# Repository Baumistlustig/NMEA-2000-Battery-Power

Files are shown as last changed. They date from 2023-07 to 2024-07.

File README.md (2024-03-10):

# NMEA 2000 Battery Power

This is a project, which reads the voltage and current of a battery, and posts it to a NMEA 2000 BUS.

The project uses an ESP32 & the SN65HVD230 for CAN BUS communication. If the voltage falls under a certain value, a contactor will automatically disconnect the battery from the rest of the circuit to prevent drain. 

Additionally, it posts the voltage, current and temperature into the N2k bus where it can be worked with by other devices.

## Table of Contents

- [Electrical](/Electrical) A KiCad project 
- [Software](/Software) A PlatformIO project

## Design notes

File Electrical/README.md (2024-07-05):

  # Electrical

  The KiCad project

  ## Table of Contents

  - [Symbol](/Electrical/Symbol) The Symbols for the schematics
  - [Datasheets](/Electrical/Datasheets) Datasheets of the components
  - [3D-Models](/Electrical/3D-Models) 3D-Models for the PCB
  - [Footprints](/Electrical/Footprints) Footprins for the PCB

## Components-List

A list of all the electrical components I used for the project:

- [ESP32 WROOM-32E](/Electrical/Datasheets/esp32-wroom-32e.pdf) Microcontroller
- [SN65HVD230](/Electrical/Datasheets/sn76hvd230.pdf) CAN Transceiver
- [BME280](/Electrical/Datasheets/bme280.pdf) Environment temp- & humidity sensor
- [ADS131M08](/Electrical/Datasheets/ads131m08-q1.pdf) 24-bit, 8 channel ADC
- [HO 150-S-SP30.pdf](/Electrical/Datasheets/HO-150-S-SP30.pdf) 150A current transducer
- [IRFZ44N](/Electrical/Datasheets/IRFZ44N.pdf) N-Channel MOSFET
- [LM7850](/Electrical/Datasheets/MC7800-D.PDF) 12-5V voltage regulator
- [AMS1117](/Electrical/Datasheets/ams1117.pdf) 5-3.3V voltage regulator
- [B57703M](/Electrical/Datasheets/B57703M-Thermistor.pdf) 10k NTC Thermistor
- ([ADR4533](/Electrical/Datasheets/ADR4533.pdf) 3.3V reference voltage source)

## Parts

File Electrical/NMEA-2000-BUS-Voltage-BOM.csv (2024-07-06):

Reference | Value | Datasheet | Footprint | Qty | DNP
C1,C2,C5,C6,C9,C13,C14,C16,C17,C19,C20,C23,C25,C28,C30 | 0.1uF | ~ | Capacitor_THT:C_Disc_D5.0mm_W2.5mm_P5.00mm | 15
C3,C7,C12,C15 | 20pF | ~ | Capacitor_THT:C_Disc_D5.0mm_W2.5mm_P5.00mm | 4
C4,C11 | 0.33uF | ~ | Capacitor_THT:C_Disc_D5.0mm_W2.5mm_P5.00mm | 2
C8,C21,C22,C24,C26 | 10nF | ~ | Capacitor_THT:C_Disc_D5.0mm_W2.5mm_P5.00mm | 5
C10,C27 | 1uF | ~ | Capacitor_THT:C_Disc_D5.0mm_W2.5mm_P5.00mm | 2
C18 | 0.1nF | ~ | Capacitor_THT:C_Disc_D5.0mm_W2.5mm_P5.00mm | 1
C29 | 220nF | ~ | Capacitor_THT:C_Disc_D5.0mm_W2.5mm_P5.00mm | 1
D1,D6,D7 | 1N5819 | ~ | Diode_THT:D_DO-41_SOD81_P10.16mm_Horizontal | 3
D2,D3,D4,D5 | LED | ~ | LED_THT:LED_D5.0mm | 4
F1 | Polyfuse | ~ | Diode_SMD:D_1210_3225Metric_Pad1.42x2.65mm_HandSolder | 1
IC1 | ADS131M08 | https://www.ti.com/lit/ds/symlink/ads131m08-q1.pdf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 | ADS131M08QPBSRQ1:QFP50P700X700X120-32N | 1
J1,J2,J4 | Conn_01x04 | ~ | -- mixed values -- | 3
J3 | Conn_02x08_Counter_Clockwise | ~ | Connector_PinHeader_2.54mm:PinHeader_2x09_P2.54mm_Vertical | 1
J5,J6,J11 | Conn_01x05 | ~ | -- mixed values -- | 3
J7,J8,J9,J10,J12,J13 | Conn_01x02 | ~ | TerminalBlock_Phoenix:TerminalBlock_Phoenix_PT-1,5-2-5.0-H_1x02_P5.00mm_Horizontal | 6
JP1,JP2 | Jumper_2_Open | ~ | Connector_PinHeader_2.54mm:PinHeader_1x02_P2.54mm_Vertical | 2
JP6,JP7 | Jumper_2_Bridged | ~ | Connector_PinHeader_2.54mm:PinHeader_1x02_P2.54mm_Vertical | 2
L1 | CBG322513U102T | ~ | Inductor_SMD:L_1210_3225Metric_Pad1.42x2.65mm_HandSolder | 1
Q1,Q2 | IRFZ44N | https://www.infineon.com/dgdl/Infineon-IRFZ44N-DataSheet-v01_01-EN.pdf?fileId=5546d462533600a40153563b3a9f220d | Package_TO_SOT_THT:TO-220-3_Vertical | 2
R1,R3,R9,R11,R13,R14,R15,R17,R18,R25,R26 | 10k | ~ | Resistor_THT:R_Axial_DIN0207_L6.3mm_D2.5mm_P10.16mm_Horizontal | 11
R2 | 0R | ~ | Resistor_THT:R_Axial_DIN0207_L6.3mm_D2.5mm_P10.16mm_Horizontal | 1
R4 | 1.2k | ~ | Resistor_THT:R_Axial_DIN0207_L6.3mm_D2.5mm_P10.16mm_Horizontal | 1
R5 | 470R | ~ | Resistor_THT:R_Axial_DIN0207_L6.3mm_D2.5mm_P10.16mm_Horizontal | 1
R6 | 330R | ~ | Resistor_THT:R_Axial_DIN0207_L6.3mm_D2.5mm_P10.16mm_Horizontal | 1
R7 | 1k5 | ~ | Resistor_THT:R_Axial_DIN0207_L6.3mm_D2.5mm_P10.16mm_Horizontal | 1
R8,R23,R24 | 120R | ~ | Resistor_THT:R_Axial_DIN0207_L6.3mm_D2.5mm_P10.16mm_Horizontal | 3
R10 | 3.3k | ~ | Resistor_THT:R_Axial_DIN0207_L6.3mm_D2.5mm_P10.16mm_Horizontal | 1
R12,R16 | 4k7 | ~ | Resistor_THT:R_Axial_DIN0207_L6.3mm_D2.5mm_P10.16mm_Horizontal | 2
R19,R20,R21,R22 | 1k | ~ | Resistor_THT:R_Axial_DIN0207_L6.3mm_D2.5mm_P10.16mm_Horizontal | 4
SW1,SW2 | SW_Push | ~ | Button_Switch_THT:SW_PUSH_6mm | 2
TP1 | 12V | ~ | TestPoint:TestPoint_Pad_3.0x3.0mm | 1
TP2 | 5V | ~ | TestPoint:TestPoint_Pad_3.0x3.0mm | 1
TP3 | 3.3V | ~ | TestPoint:TestPoint_Pad_3.0x3.0mm | 1
TP4 | VMot | ~ | TestPoint:TestPoint_Pad_3.0x3.0mm | 1
U1 | LM7805_TO220 | https://www.onsemi.cn/PowerSolutions/document/MC7800-D.PDF | Package_TO_SOT_THT:TO-220-3_Vertical | 1
U2 | AMS1117-3.3 | http://www.advanced-monolithic.com/pdf/ds1117.pdf | Package_TO_SOT_SMD:SOT-223-3_TabPin2 | 1
U3 | STM32G431CBTx | https://www.st.com/resource/en/datasheet/stm32g431cb.pdf | Package_QFP:LQFP-48_7x7mm_P0.5mm | 1
U4 | MCP2562-E-P | http://ww1.microchip.com/downloads/en/DeviceDoc/25167A.pdf | Package_DIP:DIP-8_W7.62mm | 1
U5 | BMP280 | https://ae-bst.resource.bosch.com/media/_tech/media/datasheets/BST-BMP280-DS001.pdf | N2K-influx:Bosch_LGA-8_2x2.5mm_P0.65mm_ClockwisePinNumbering | 1
U6 | ADR4533 | https://www.analog.com/media/en/technical-documentation/data-sheets/ADR4520_4525_4530_4533_4540_4550.pdf | Package_SO:SOIC-8_3.9x4.9mm_P1.27mm | 1
Y1 | K7A080002020 | ~ | Crystal:Crystal_SMD_7050-4Pin_7.0x5.0mm | 1
Y2 | X308032768KGB2SC | ~ | Crystal:Crystal_C38-LF_D3.0mm_L8.0mm_Horizontal | 1
Y3 | 20kHz Crystal | ~ | Crystal:Crystal_AT310_D3.0mm_L10.0mm_Horizontal | 1

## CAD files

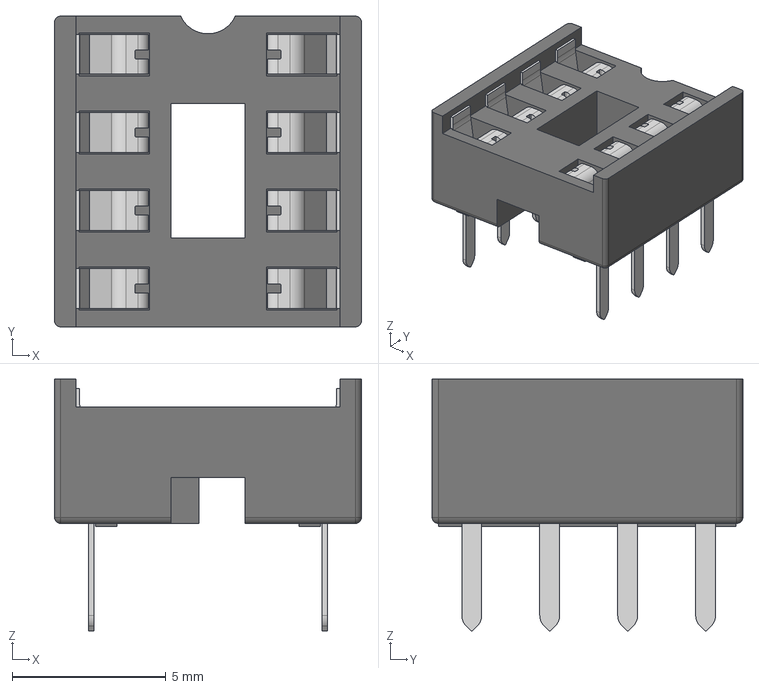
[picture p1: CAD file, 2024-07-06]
Electrical/3D-Models/Socket_DIP8.stp
10.0 x 10.1 x 8.20 mm

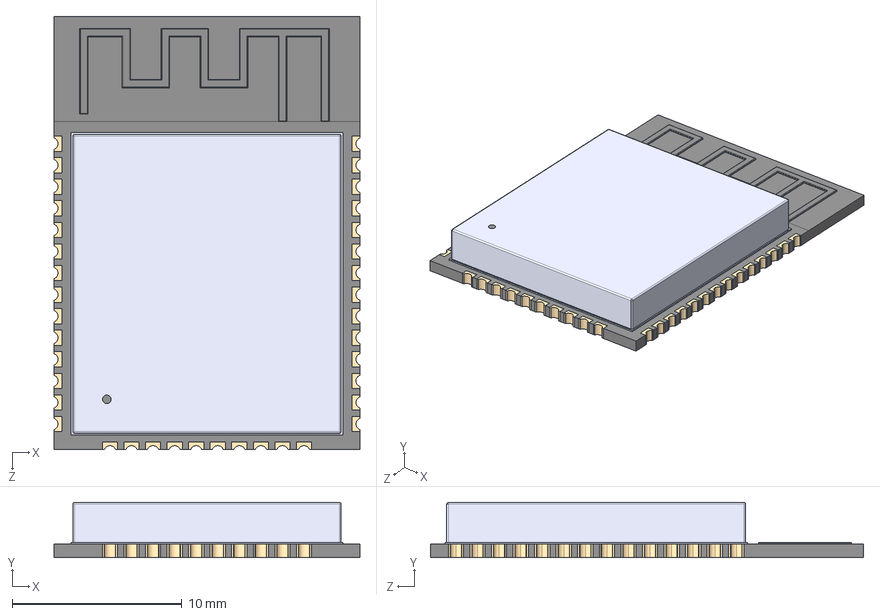
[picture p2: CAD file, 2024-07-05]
Electrical/3D-Models/ESP32-WROOM-32E (16MB).STEP
18.0 x 3.25 x 25.5 mm

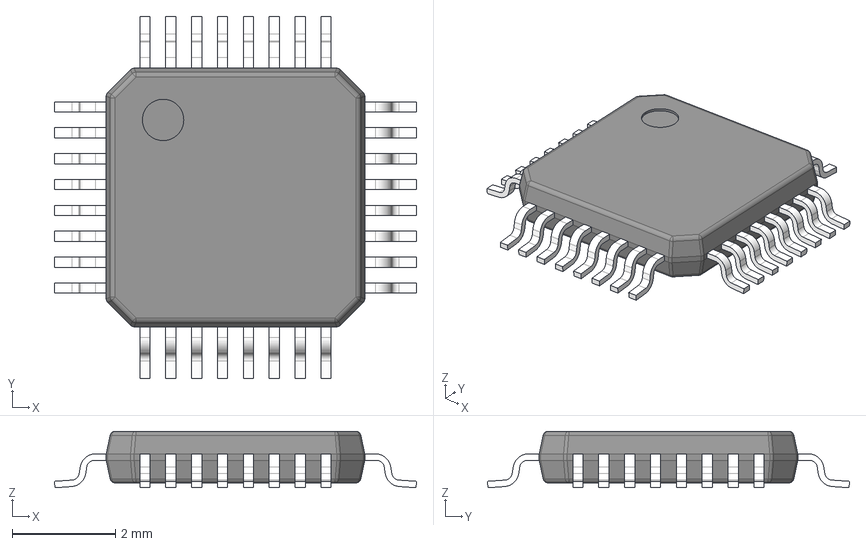
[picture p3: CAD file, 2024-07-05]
Electrical/3D-Models/ADS131M08QPBSRQ1.stp
7.00 x 7.00 x 1.09 mm
BODY-TQFP
LEAD-TQFP x 32
PIN1

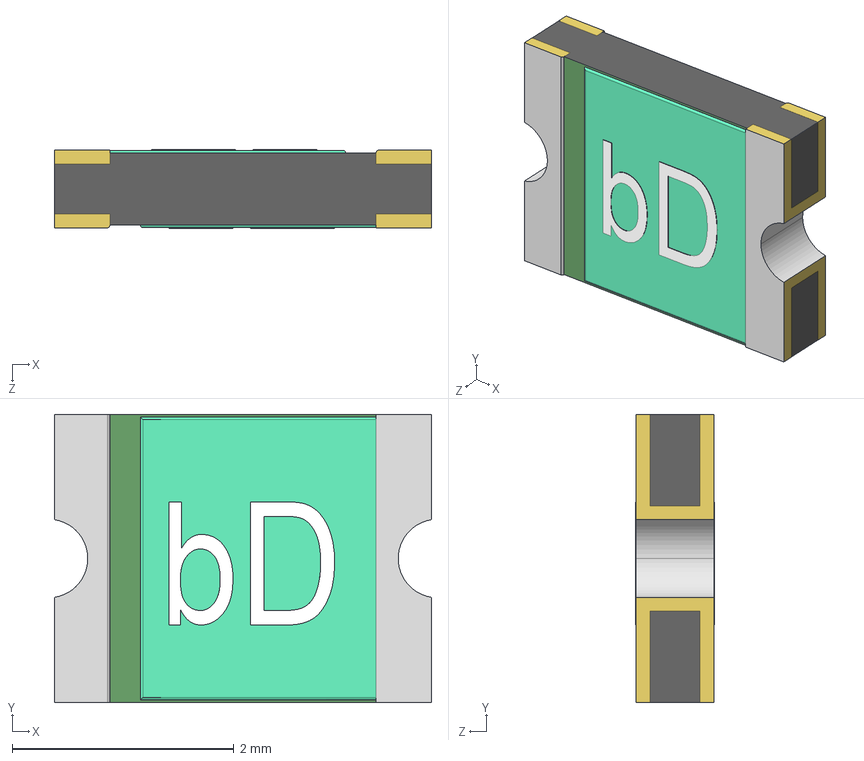
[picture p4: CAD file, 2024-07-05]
Electrical/3D-Models/Resetable Fuse 1210.step
3.40 x 2.60 x 0.708 mm

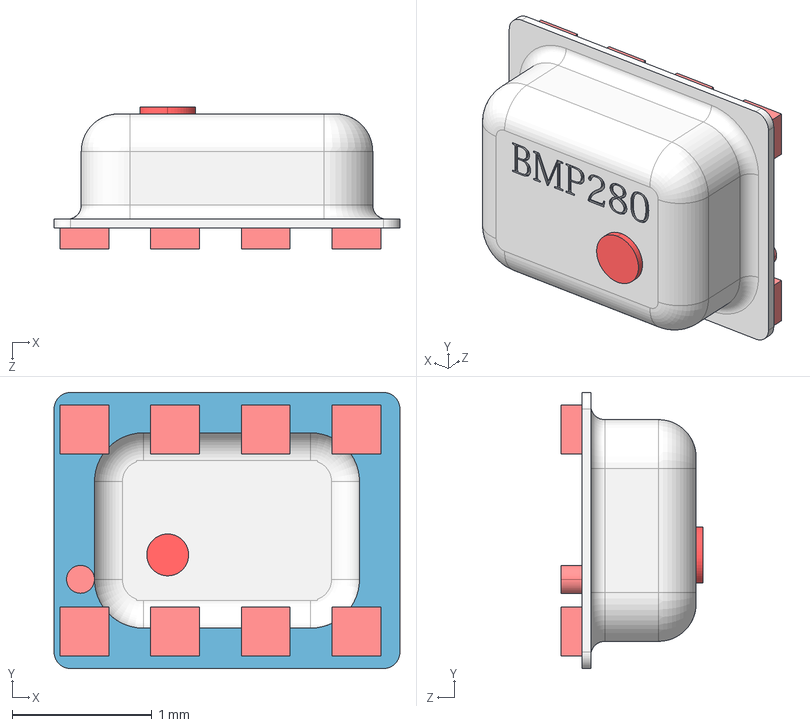
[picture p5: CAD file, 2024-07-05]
Electrical/3D-Models/BMP-280.STEP
2.48 x 1.98 x 1.02 mm

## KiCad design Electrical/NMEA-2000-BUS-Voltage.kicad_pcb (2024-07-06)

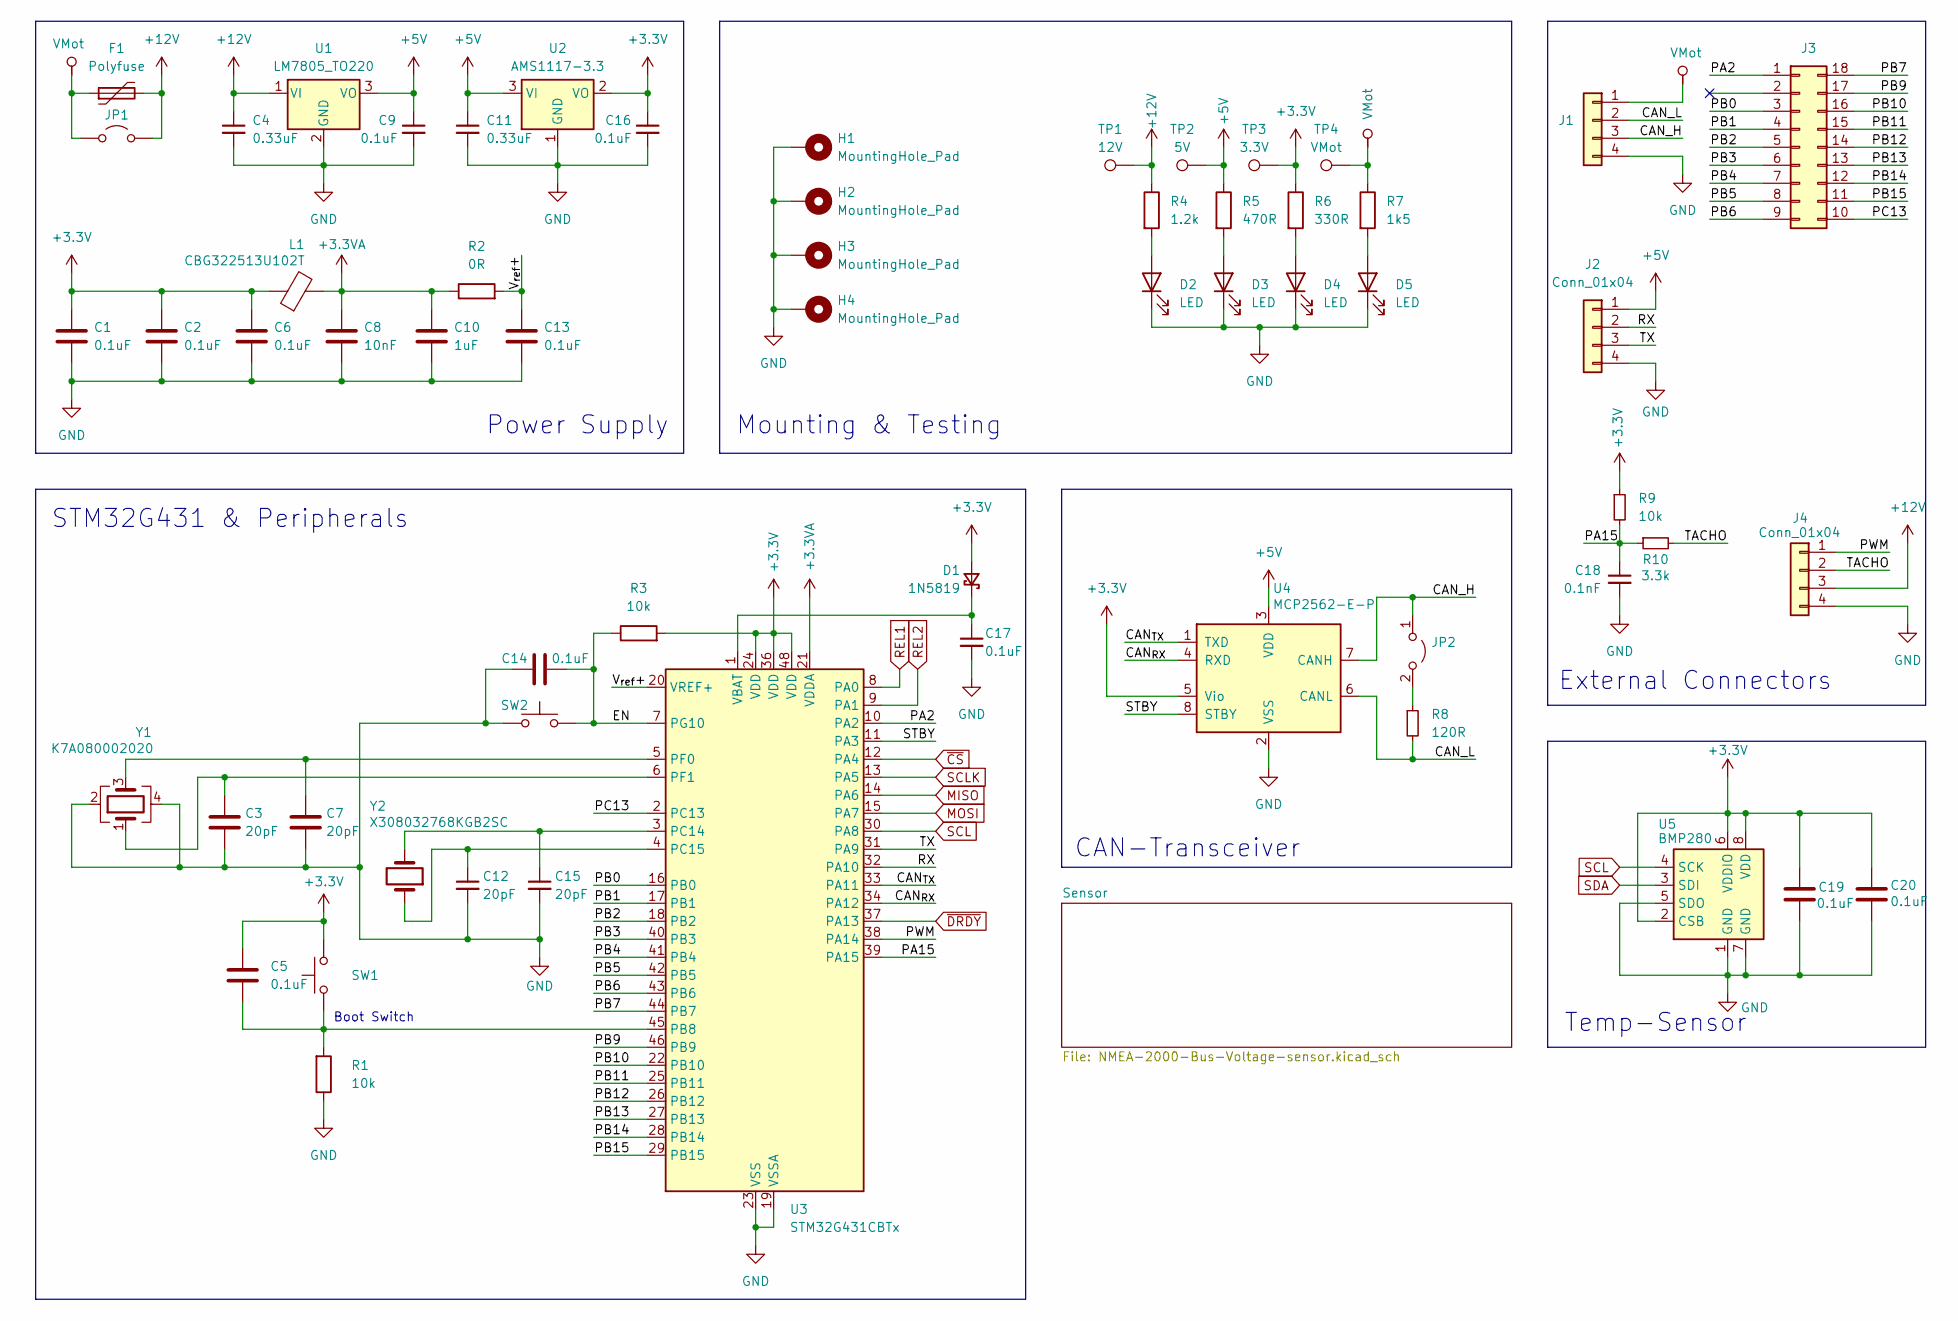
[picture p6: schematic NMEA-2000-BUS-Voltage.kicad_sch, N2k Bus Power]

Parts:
C1, C2, C5, C6, C9, C13, C14, C16, C17, C19, C20: 0.1uF; C_Disc_D5.0mm_W2.5mm_P5.00mm
C3, C7, C12, C15: 20pF; C_Disc_D5.0mm_W2.5mm_P5.00mm
C4, C11: 0.33uF; C_Disc_D5.0mm_W2.5mm_P5.00mm
C8: 10nF; C_Disc_D5.0mm_W2.5mm_P5.00mm
C10: 1uF; C_Disc_D5.0mm_W2.5mm_P5.00mm
C18: 0.1nF; C_Disc_D5.0mm_W2.5mm_P5.00mm
D1: 1N5819; D_DO-41_SOD81_P10.16mm_Horizontal
D2, D3, D4, D5: LED; LED_D5.0mm
F1: Polyfuse; D_1210_3225Metric_Pad1.42x2.65mm_HandSolder
H1, H2, H3, H4: MountingHole_Pad; MountingHole_6mm_Pad
J1: Conn_01x04; TerminalBlock_Phoenix_PT-1,5-4-5.0-H_1x04_P5.00mm_Horizontal
J2: Conn_01x04; PinSocket_1x04_P2.54mm_Horizontal
J3: Conn_02x08_Counter_Clockwise; PinHeader_2x09_P2.54mm_Vertical
J4: Conn_01x04; FanPinHeader_1x04_P2.54mm_Vertical
JP1, JP2: Jumper_2_Open; PinHeader_1x02_P2.54mm_Vertical
L1: CBG322513U102T; L_1210_3225Metric_Pad1.42x2.65mm_HandSolder
R1, R3, R9: 10k; R_Axial_DIN0207_L6.3mm_D2.5mm_P10.16mm_Horizontal
R2: 0R; R_Axial_DIN0207_L6.3mm_D2.5mm_P10.16mm_Horizontal
R4: 1.2k; R_Axial_DIN0207_L6.3mm_D2.5mm_P10.16mm_Horizontal
R5: 470R; R_Axial_DIN0207_L6.3mm_D2.5mm_P10.16mm_Horizontal
R6: 330R; R_Axial_DIN0207_L6.3mm_D2.5mm_P10.16mm_Horizontal
R7: 1k5; R_Axial_DIN0207_L6.3mm_D2.5mm_P10.16mm_Horizontal
R8: 120R; R_Axial_DIN0207_L6.3mm_D2.5mm_P10.16mm_Horizontal
R10: 3.3k; R_Axial_DIN0207_L6.3mm_D2.5mm_P10.16mm_Horizontal
SW1, SW2: SW_Push; SW_PUSH_6mm
TP1: 12V; TestPoint_Pad_3.0x3.0mm
TP2: 5V; TestPoint_Pad_3.0x3.0mm
TP3: 3.3V; TestPoint_Pad_3.0x3.0mm
TP4: VMot; TestPoint_Pad_3.0x3.0mm
U1: LM7805_TO220; TO-220-3_Vertical
U2: AMS1117-3.3; SOT-223-3_TabPin2
U3: STM32G431CBTx; LQFP-48_7x7mm_P0.5mm
U4: MCP2562-E-P; DIP-8_W7.62mm
U5: BMP280; Bosch_LGA-8_2x2.5mm_P0.65mm_ClockwisePinNumbering
Y1: K7A080002020; Crystal_SMD_7050-4Pin_7.0x5.0mm
Y2: X308032768KGB2SC; Crystal_C38-LF_D3.0mm_L8.0mm_Horizontal

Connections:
+3.3V: C1.1, C2.1, C5.1, C6.1, C16.1, C19.1, C20.1, D1.2 (A), L1.1, R3.2, R6.1, R9.1, SW1.1, TP3.1, U2.2 (VO), U3.24 (VDD), U3.36 (VDD), U3.48 (VDD), U4.5 (Vio), U5.2 (CSB), U5.6 (VDDIO), U5.8 (VDD); also elsewhere on the board
+3.3VA: C8.1, C10.1, L1.2, R2.1, U3.21 (VDDA)
+5V: C9.1, C11.1, J2.1, R5.1, TP2.1, U1.3 (VO), U2.3 (VI), U4.3 (VDD); also elsewhere on the board
+12V: C4.1, F1.2, J4.3, JP1.2 (B), R4.1, TP1.1, U1.1 (VI); also elsewhere on the board
/CAN_H: J1.3, JP2.1 (A), U4.7 (CANH)
/CAN_L: J1.2, R8.2, U4.6 (CANL)
/CAN_{RX}: U3.34 (PA12), U4.4 (RXD)
/CAN_{TX}: U3.33 (PA11), U4.1 (TXD)
/EN: C14.2, R3.1, SW2.2, U3.7 (PG10)
/PA2: J3.1, U3.10 (PA2)
/PA15: C18.1, R9.2, R10.1, U3.39 (PA15)
/PB0: J3.3, U3.16 (PB0)
/PB1: J3.4, U3.17 (PB1)
/PB2: J3.5, U3.18 (PB2)
/PB3: J3.6, U3.40 (PB3)
/PB4: J3.7, U3.41 (PB4)
/PB5: J3.8, U3.42 (PB5)
/PB6: J3.9, U3.43 (PB6)
/PB7: J3.18, U3.44 (PB7)
/PB9: J3.17, U3.46 (PB9)
/PB10: J3.16, U3.22 (PB10)
/PB11: J3.15, U3.25 (PB11)
/PB12: J3.14, U3.26 (PB12)
/PB13: J3.13, U3.27 (PB13)
/PB14: J3.12, U3.28 (PB14)
/PB15: J3.11, U3.29 (PB15)
/PC13: J3.10, U3.2 (PC13)
/PWM: J4.1, U3.38 (PA14)
/RX: J2.2, U3.32 (PA10)
/STBY: U3.11 (PA3), U4.8 (STBY)
/TACHO: J4.2, R10.2
/TX: J2.3, U3.31 (PA9)
/V_{ref}+: C13.1, R2.2, U3.20 (VREF+)
GND: C1.2, C2.2, C3.2, C4.2, C6.2, C7.2, C8.2, C9.2, C10.2, C11.2, C12.2, C13.2, C14.1, C15.2, C16.2, C17.2, C18.2, C19.2, C20.2, D2.1 (K), D3.1 (K), D4.1 (K), D5.1 (K), H1.1, H2.1, H3.1, H4.1, J1.4, J2.4, J4.4, R1.1, SW2.1, U1.2 (GND), U2.1 (GND), U3.19 (VSSA), U3.23 (VSS), U3.35 (VSS), U3.47 (VSS), U4.2 (VSS), U5.1 (GND), U5.5 (SDO), U5.7 (GND), Y1.2, Y1.4; also elsewhere on the board
MISO: U3.14 (PA6); also elsewhere on the board
MOSI: U3.15 (PA7); also elsewhere on the board
unnamed: C17.1, D1.1 (K), U3.1 (VBAT)
unnamed: D2.2 (A), R4.2
unnamed: D3.2 (A), R5.2
unnamed: D4.2 (A), R6.2
unnamed: D5.2 (A), R7.2
unnamed: JP2.2 (B), R8.1
unnamed: C5.2, R1.2, SW1.2, U3.45 (PB8)
unnamed: C15.1, U3.3 (PC14), Y2.2
unnamed: C12.1, U3.4 (PC15), Y2.1
unnamed: C7.1, U3.5 (PF0), Y1.3
unnamed: C3.1, U3.6 (PF1), Y1.1
REL1: U3.8 (PA0); also elsewhere on the board
REL2: U3.9 (PA1); also elsewhere on the board
SCL: U3.30 (PA8), U5.4 (SCK)
SCLK: U3.13 (PA5); also elsewhere on the board
SDA: U5.3 (SDI)
VMot: F1.1, J1.1, JP1.1 (A), R7.1, TP4.1
~CS: U3.12 (PA4); also elsewhere on the board
~DRDY: U3.37 (PA13); also elsewhere on the board

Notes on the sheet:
Power Supply
Mounting & Testing
STM32G431 & Peripherals
Boot Switch
External Connectors
CAN-Transceiver
Temp-Sensor

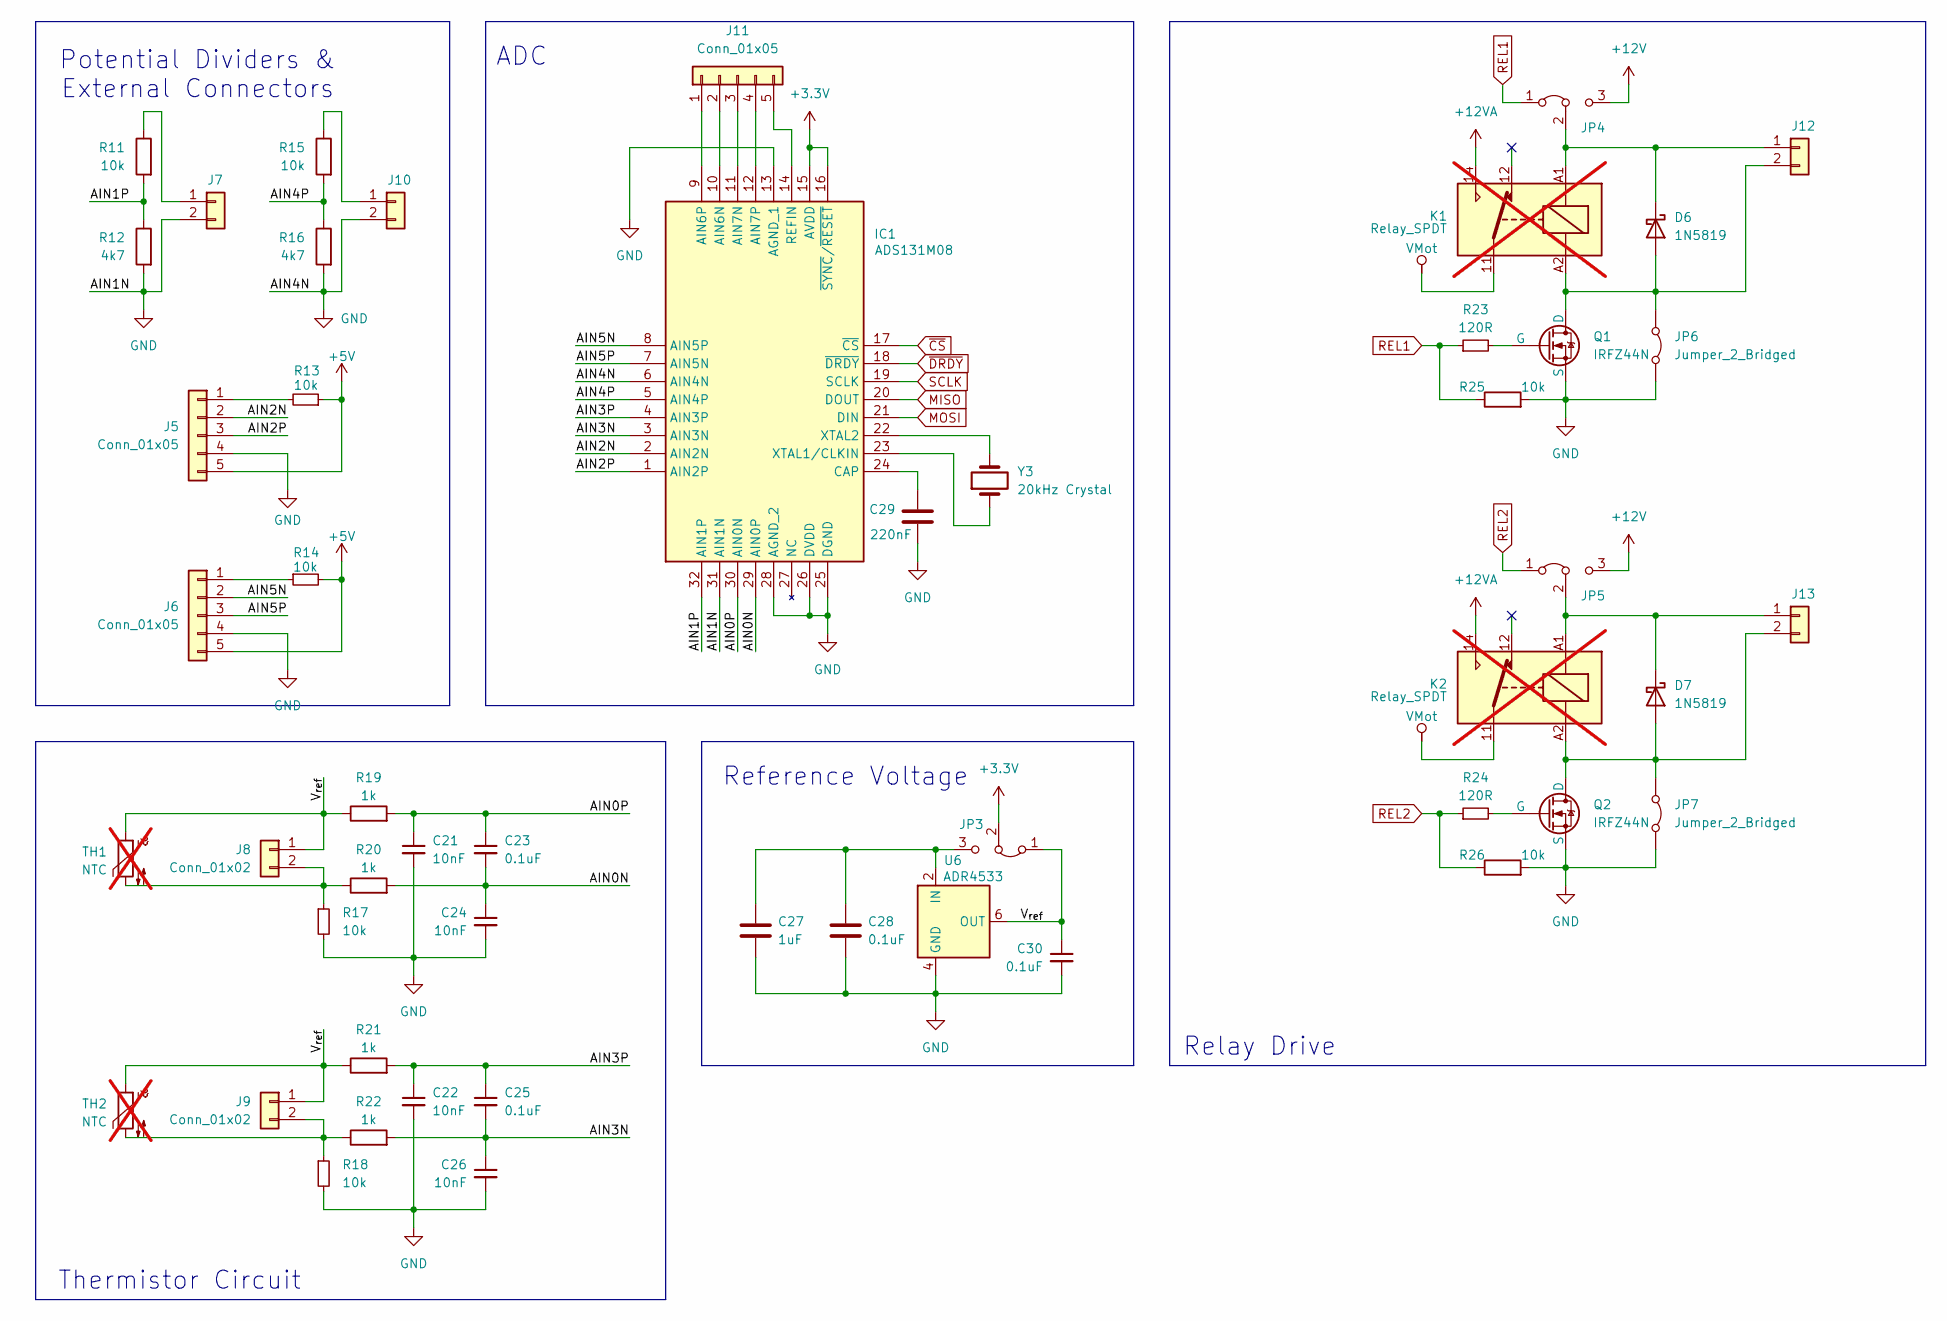
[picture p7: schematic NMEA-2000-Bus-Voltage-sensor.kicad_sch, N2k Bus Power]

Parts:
C21, C22, C24, C26: 10nF; C_Disc_D5.0mm_W2.5mm_P5.00mm
C23, C25, C28, C30: 0.1uF; C_Disc_D5.0mm_W2.5mm_P5.00mm
C27: 1uF; C_Disc_D5.0mm_W2.5mm_P5.00mm
C29: 220nF; C_Disc_D5.0mm_W2.5mm_P5.00mm
D6, D7: 1N5819; D_DO-41_SOD81_P10.16mm_Horizontal
IC1: ADS131M08; QFP50P700X700X120-32N; Mouser Part Number 595-ADS131M08QPBSRQ1
J5, J6: Conn_01x05; TerminalBlock_Phoenix_PT-1,5-5-5.0-H_1x05_P5.00mm_Horizontal
J7, J8, J9, J10, J12, J13: Conn_01x02; TerminalBlock_Phoenix_PT-1,5-2-5.0-H_1x02_P5.00mm_Horizontal
J11: Conn_01x05; PinHeader_1x05_P2.54mm_Vertical
JP3, JP4, JP5: Jumper_3_Bridged12; PinHeader_1x03_P2.54mm_Vertical
JP6, JP7: Jumper_2_Bridged; PinHeader_1x02_P2.54mm_Vertical
K1, K2: Relay_SPDT; not fitted
Q1, Q2: IRFZ44N; TO-220-3_Vertical
R11, R13, R14, R15, R17, R18, R25, R26: 10k; R_Axial_DIN0207_L6.3mm_D2.5mm_P10.16mm_Horizontal
R12, R16: 4k7; R_Axial_DIN0207_L6.3mm_D2.5mm_P10.16mm_Horizontal
R19, R20, R21, R22: 1k; R_Axial_DIN0207_L6.3mm_D2.5mm_P10.16mm_Horizontal
R23, R24: 120R; R_Axial_DIN0207_L6.3mm_D2.5mm_P10.16mm_Horizontal
TH1, TH2: NTC; not fitted
U6: ADR4533; SOIC-8_3.9x4.9mm_P1.27mm
Y3: 20kHz Crystal; Crystal_AT310_D3.0mm_L10.0mm_Horizontal

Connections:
+3.3V: IC1.15 (AVDD), IC1.16 (~SYNC/~RESET), JP3.2 (C); also elsewhere on the board
+5V: J5.5, J6.5, R13.1, R14.2; also elsewhere on the board
+12V: JP4.3 (B), JP5.3 (B); also elsewhere on the board
/Sensor/AIN0N: C23.2, C24.1, IC1.29 (AIN0P), R20.2
/Sensor/AIN0P: C21.1, C23.1, IC1.30 (AIN0N), R19.2
/Sensor/AIN1P: IC1.32 (AIN1P), R11.2, R12.1
/Sensor/AIN2N: IC1.2 (AIN2N), J5.2
/Sensor/AIN2P: IC1.1 (AIN2P), J5.3
/Sensor/AIN3N: C25.2, C26.1, IC1.3 (AIN3N), R22.2
/Sensor/AIN3P: C22.1, C25.1, IC1.4 (AIN3P), R21.2
/Sensor/AIN4P: IC1.5 (AIN4P), R15.2, R16.1
/Sensor/AIN5N: IC1.8 (AIN5P), J6.2
/Sensor/AIN5P: IC1.7 (AIN5N), J6.3
/Sensor/V_{ref}: C30.1, J8.1, J9.1, JP3.1 (A), R19.1, R21.1, TH1.1, TH2.1, U6.6 (OUT)
GND: C21.2, C22.2, C24.2, C26.2, C27.2, C28.2, C29.2, C30.2, IC1.6 (AIN4N), IC1.13 (AGND_1), IC1.25 (DGND), IC1.26 (DVDD), IC1.28 (AGND_2), IC1.31 (AIN1N), J5.4, J6.4, J7.2, J10.2, JP6.2 (B), JP7.2 (B), Q1.3 (S), Q2.3 (S), R12.2, R16.2, R17.2, R18.2, R25.2, R26.2, U6.4 (GND); also elsewhere on the board
MISO: IC1.20 (DOUT); also elsewhere on the board
MOSI: IC1.21 (DIN); also elsewhere on the board
unnamed: D6.2 (A), J12.2, JP6.1 (A), K1.A2, Q1.1 (D)
unnamed: D6.1 (K), J12.1, JP4.2 (C), K1.A1
unnamed: D7.2 (A), J13.2, JP7.1 (A), K2.A2, Q2.1 (D)
unnamed: D7.1 (K), J13.1, JP5.2 (C), K2.A1
unnamed: IC1.10 (AIN6N), J11.2
unnamed: IC1.9 (AIN6P), J11.1
unnamed: IC1.11 (AIN7N), J11.3
unnamed: IC1.12 (AIN7P), J11.4
unnamed: C29.1, IC1.24 (CAP)
unnamed: IC1.14 (REFIN), J11.5
unnamed: IC1.23 (XTAL1/CLKIN), Y3.1
unnamed: IC1.22 (XTAL2), Y3.2
unnamed: J5.1, R13.2
unnamed: J6.1, R14.1
unnamed: J7.1, R11.1
unnamed: J8.2, R17.1, R20.1, TH1.2
unnamed: J9.2, R18.1, R22.1, TH2.2
unnamed: J10.1, R15.1
unnamed: C27.1, C28.1, JP3.3 (B), U6.2 (IN)
unnamed: K1.11, K2.11
unnamed: K1.14, K2.14
unnamed: Q1.2 (G), R23.2
unnamed: Q2.2 (G), R24.2
REL1: JP4.1 (A), R23.1, R25.1; also elsewhere on the board
REL2: JP5.1 (A), R24.1, R26.1; also elsewhere on the board
SCLK: IC1.19 (SCLK); also elsewhere on the board
~CS: IC1.17 (~CS); also elsewhere on the board
~DRDY: IC1.18 (~DRDY); also elsewhere on the board

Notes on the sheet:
Potential Dividers & External Connectors
Reference Voltage
Relay Drive
Thermistor Circuit
ADC

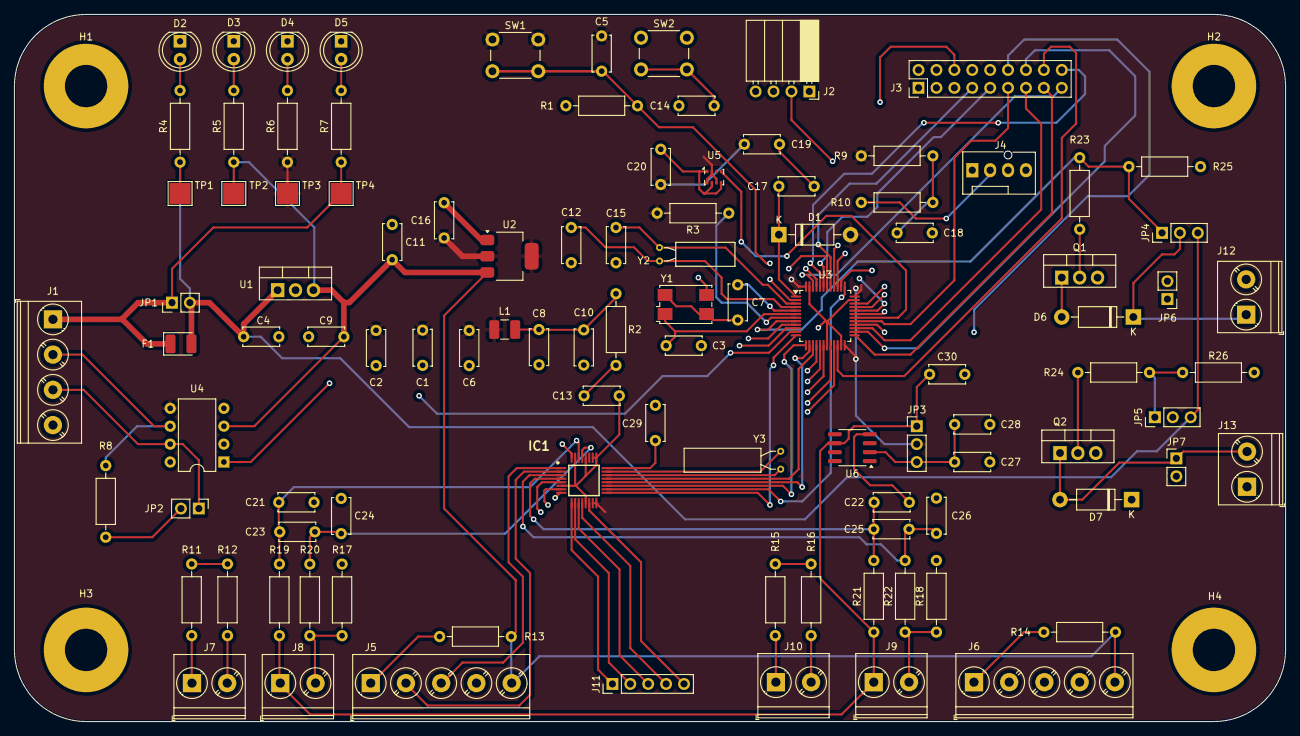
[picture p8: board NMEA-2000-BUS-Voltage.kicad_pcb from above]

Board: 4 copper layers, 180.3 x 100.3 mm, 107 parts (0 on the bottom side), 86 nets.

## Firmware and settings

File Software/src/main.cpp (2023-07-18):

#include <Arduino.h>
#include <Preferences.h>
#include <NMEA2000_CAN.h>
#include <N2kMessages.h>
#include <Wire.h>
#include <Adafruit_BMP280.h>

#define ESP32_CAN_TX_PIN GPIO_NUM_5  // Set CAN TX port to 5 
#define ESP32_CAN_RX_PIN GPIO_NUM_4  // Set CAN RX port to 4

#define ADCpin1 34                   // GPIO 34 (Analog input, ADC1_CH6)
#define ADC_Calibration_Value1 250.0 // For resistor measure 5 Volt and 180 Ohm equals 100% plus 1K resistor.

#define ADCpin2 35                   // GPIO 35 (Analog input, ADC1_CH7))
#define ADC_Calibration_Value2 34.3  // To measure battery voltage. The real value depends on the true resistor values for the ADC input (100K / 27 K).


// Set time offsets
#define SlowDataUpdatePeriod 1000  // Time between CAN Messages sent
#define BatteryVoltageSendOffset 0
#define WaterTankLevelSendOffset 50

Adafruit_BMP280 bmp;

int NodeAddress;            // To store last Node Address
Preferences preferences; 

const unsigned long TransmitMessages[] PROGMEM = {
  127508L, // Battery Status
  127505L, // Fluid level
  0
};

// Define all Function Codes
void CheckSourceAddressChange();
void sendBatteryInfo(void);
bool IsTimeToUpdate(unsigned long NextUpdate);
unsigned long InitNextUpdate(unsigned long Period, unsigned long Offset = 0);
void SetNextUpdate(unsigned long & NextUpdate, unsigned long Period);
double ReadADC(byte pin);

void setup() {
  
  uint8_t chipid[6];
  uint32_t id = 0;
  int i = 0;

  // Init USB serial port
  Serial.begin(115200);
  delay(10);

  if (!bmp.begin()) {
    Serial.println(F("Could not find a valid BMP280 sensor, check wiring or "
                      "try a different address!"));
    Serial.print("SensorID was: 0x"); Serial.println(bmp.sensorID(),16);
    Serial.print("        ID of 0xFF probably means a bad address, a BMP 180 or BMP 085\n");
    Serial.print("   ID of 0x56-0x58 represents a BMP 280,\n");
    Serial.print("        ID of 0x60 represents a BME 280.\n");
    Serial.print("        ID of 0x61 represents a BME 680.\n");
    while (1) delay(10);

    bmp.setSampling(
      Adafruit_BMP280::MODE_NORMAL,     /* Operating Mode. */
      Adafruit_BMP280::SAMPLING_X2,     /* Temp. oversampling */
      Adafruit_BMP280::SAMPLING_X16,    /* Pressure oversampling */
      Adafruit_BMP280::FILTER_X16,      /* Filtering. */
      Adafruit_BMP280::STANDBY_MS_500   /* Standby time. */
    );
  }

  // Reserve enough buffer for sending all messages.
  NMEA2000.SetN2kCANMsgBufSize(8);
  NMEA2000.SetN2kCANReceiveFrameBufSize(150);
  NMEA2000.SetN2kCANSendFrameBufSize(150);

  // Generate unique number from chip id
  esp_efuse_mac_get_default(chipid);
  for (i = 0; i < 6; i++) id += (chipid[i] << (7 * i));

  // Set product information
  NMEA2000.SetProductInformation(
    "1", // Manufacturer's Model serial code
    100, // Manufacturer's product code
    "My Sensor Module",  // Manufacturer's Model ID
    "1.0.2.25 (2019-07-07)",  // Manufacturer's Software version code
    "1.0.2.0 (2019-07-07)" // Manufacturer's Model version
  );

  // Set device information
  NMEA2000.SetDeviceInformation(
    id, // Unique number. Use e.g. Serial number.
    132, // Device function=Analog to NMEA 2000 Gateway. See codes on http://www.nmea.org/Assets/20120726%20nmea%202000%20class%20&%20function%20codes%20v%202.00.pdf
    25, // Device class=Inter/Intranetwork Device. See codes on  http://www.nmea.org/Assets/20120726%20nmea%202000%20class%20&%20function%20codes%20v%202.00.pdf
    2046 // Just choosen free from code list on http://www.nmea.org/Assets/20121020%20nmea%202000%20registration%20list.pdf
  );

  preferences.begin("nvs", false);                          // Open nonvolatile storage (nvs)
  NodeAddress = preferences.getInt("LastNodeAddress", 34);  // Read stored last NodeAddress, default 34
  preferences.end();
  Serial.printf("NodeAddress=%d\n", NodeAddress);

  // If you also want to see all traffic on the bus use N2km_ListenAndNode instead of N2km_NodeOnly below
  NMEA2000.SetMode(tNMEA2000::N2km_NodeOnly, NodeAddress);
  NMEA2000.ExtendTransmitMessages(TransmitMessages);

  NMEA2000.Open();

  delay(200);
}

void loop() {

  sendBatteryInfo();
  
  NMEA2000.ParseMessages();

  CheckSourceAddressChange();
  
  // Dummy to empty input buffer to avoid board to stuck with e.g. NMEA Reader
  if ( Serial.available() ) {
    Serial.read();
  }
}

void CheckSourceAddressChange() {
  int SourceAddress = NMEA2000.GetN2kSource();

  if (SourceAddress != NodeAddress) { // Save potentially changed Source Address to NVS memory
    NodeAddress = SourceAddress;      // Set new Node Address (to save only once)
    preferences.begin("nvs", false);
    preferences.putInt("LastNodeAddress", SourceAddress);
    preferences.end();
    Serial.printf("Address Change: New Address=%d\n", SourceAddress);
  }
}

void sendBatteryInfo(void) {
  static unsigned long SlowDataUpdated = InitNextUpdate(SlowDataUpdatePeriod, BatteryVoltageSendOffset);
  tN2kMsg N2kMsg;
  double BatteryVoltage;
  double BatteryCurrent;
  float BatteryTemperature;

  if ( IsTimeToUpdate(SlowDataUpdated) ) {
    SetNextUpdate(SlowDataUpdated, SlowDataUpdatePeriod);

    // Read BatteryVoltage on ADCpin1
    BatteryVoltage = ReadADC(ADCpin1) * ADC_Calibration_Value1 / 4096;

    // Read BatteryCurrent on ADCpin2
    BatteryCurrent = ReadADC(ADCpin2) * ADC_Calibration_Value2 / 4096;

    // Read BatteryTemperature on BMP280
    BatteryTemperature = bmp.readTemperature();

    // Print values
    Serial.printf(
      "Battery: Voltage: %3.1f V, Current %3.1f A, Temperature: %3.1f \n",
      BatteryVoltage, BatteryCurrent, BatteryTemperature
    );

    // Set N2K message
    SetN2kPGN127508(N2kMsg, 0, BatteryVoltage, BatteryCurrent, BatteryTemperature, 0);

    // Send message
    NMEA2000.SendMsg(N2kMsg);
  }
}

bool IsTimeToUpdate(unsigned long NextUpdate) {
  return (NextUpdate < millis());
}

unsigned long InitNextUpdate(unsigned long Period, unsigned long Offset) {
  return millis() + Period + Offset;
}

void SetNextUpdate(unsigned long & NextUpdate, unsigned long Period) {
  while ( NextUpdate < millis() ) NextUpdate += Period;
}

double ReadADC(byte pin) {
  double reading = analogRead(pin); // Reference voltage is 3v3 so maximum reading is 3v3 = 4095 in range 0 to 4095
  if (reading < 1 || reading > 4095) return 0;
  // return -0.000000000009824 * pow(reading,3) + 0.000000016557283 * pow(reading,2) + 0.000854596860691 * reading + 0.065440348345433;
  return (-0.000000000000016 * pow(reading, 4) + 0.000000000118171 * pow(reading, 3) - 0.000000301211691 * pow(reading, 2) + 0.001109019271794 * reading + 0.034143524634089) * 1000;
} // Added an improved polynomial, use either, comment out as required

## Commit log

2023-04-11 Initialized Kicad Project
2023-04-11 Added Schematic
    [battery-percentage.kicad_sch]
2023-04-11 Added PCB Design
    [battery-percentage.kicad_pcb]
2023-04-11 Added TTl Interface to Schematic
    [battery-percentage.kicad_sch]
2023-04-11 Added TTl Interface to PCB
    [battery-percentage.kicad_pcb]
2023-04-13 Added POST / (Edit Voltage & State)
2023-04-13 Added posting voltage in script.ino
2023-04-13 Updated Potential Divider
    [battery-percentage.kicad_sch]
2023-04-20 Updated Potential Divider & Capacitor
    [battery-percentage.kicad_sch]
2023-04-27 Added Auto-Off Relay
2023-04-27 Updated PCB
    [battery-percentage.kicad_pcb]
2023-04-27 Updated Schematic
    [battery-percentage.kicad_sch]
2023-04-27 Added PDF of Schematic
2023-05-02 Updated Potential Divider Values
    [battery-percentage.kicad_sch]
2023-05-14 Added CAN BUS Connector Socket
    [battery-percentage.kicad_sch]
2023-05-14 Renamed Files
    [NMEA-2000-BUS-Voltage.kicad_pcb, NMEA-2000-BUS-Voltage.kicad_sch]
2023-05-14 Added Relay Connector
    [NMEA-2000-BUS-Voltage.kicad_sch]
2023-05-16 Added 3.3V to D1
    [NMEA-2000-BUS-Voltage.kicad_sch]
2023-05-22 Changed D1 Mini to ESP32 Wroom
    [NMEA-2000-BUS-Voltage.kicad_sch]
2023-07-08 Moved into 'Electrical Folder'
    [NMEA-2000-BUS-Voltage.kicad_pcb, NMEA-2000-BUS-Voltage.kicad_sch]
2023-07-08 Added Scheam
    [NMEA-2000-BUS-Voltage.kicad_sch]
2023-07-08 Added D1 Mini to Schematic
    [NMEA-2000-BUS-Voltage.kicad_sch]
2023-07-08 Added Potential Divider
    [NMEA-2000-BUS-Voltage.kicad_sch]
2023-07-08 Added Flash Button
    [NMEA-2000-BUS-Voltage.kicad_sch]
2023-07-08 Added LM7805
    [NMEA-2000-BUS-Voltage.kicad_sch]
2023-07-08 Added Connector
    [NMEA-2000-BUS-Voltage.kicad_sch]
2023-07-08 git status
    [NMEA-2000-BUS-Voltage.kicad_sch]
2023-07-11 Added NMEA-2000-BUS-Voltage.ino
2023-07-17 Removed Arduino Project+
2023-07-18 Removed MCP2515
    [NMEA-2000-BUS-Voltage.kicad_sch]
2023-07-18 Added SN65HVD230 Module to Schematic
    [NMEA-2000-BUS-Voltage.kicad_sch]
2023-07-18 Added BMP280-Module to Schematic
    [NMEA-2000-BUS-Voltage.kicad_sch]
2023-07-18 Added ACS712-Module to Schematic
    [NMEA-2000-BUS-Voltage.kicad_sch]
2023-07-18 Modified Schematic
    [NMEA-2000-BUS-Voltage.kicad_sch]
2023-07-18 Addedd Relay
    [NMEA-2000-BUS-Voltage.kicad_sch]
2023-07-18 Added esp32 Footprint
2023-12-11 Added 12-15V voltageboost
    [NMEA-2000-BUS-Voltage.kicad_sch]
2023-12-11 Updated Schematics
    [NMEA-2000-BUS-Voltage.kicad_sch]
2024-03-10 Updated to KiCad Version 8
2024-03-10 Added PWM Fan control
    [NMEA-2000-BUS-Voltage.kicad_sch]
2024-03-12 Added Power LEDs & 12V SDC
    [NMEA-2000-BUS-Voltage.kicad_sch]
2024-05-19 Finished Rev 1
    [NMEA-2000-BUS-Voltage.kicad_sch]
2024-05-24 Finished Rev 1 Schematics
    [NMEA-2000-BUS-Voltage.kicad_sch]
2024-05-24 Finished Rev 2 Schematics
    [NMEA-2000-BUS-Voltage.kicad_sch]
2024-05-24 Added 3D-Models
    [ADS131M08QPBSRQ1.stp, ESP32-WROOM-32E (16MB).STEP]
2024-05-29 Rename B57703M Thermistor.pdf to B57703M-Thermistor.pdf
2024-05-29 Added Schematic SVG
2024-07-05 Added BMP-280 3D-File Removed BME-280 3D-File Added Resetable Fuse 3D-File
    [BMP-280.STEP, Bme280.stp, Resetable Fuse 1210.step]
2024-07-05 Added AMS1117 Datasheet Removed AP2112 Datasheet Added BMP-280 Datasheet Added STM32 Reference Manual Removed ADS131m08-Q1 Datasheet Added ADS131m08 Datasheet Removed ESP32 Datasheet Added STM32g431C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
2024-07-05 Added ADS131M08 Footprint
2024-07-06 Replaced SN65HVD230 with MCP2562
    [NMEA-2000-BUS-Voltage.kicad_pcb, NMEA-2000-BUS-Voltage.kicad_sch, Socket_DIP8.stp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]
2024-07-06 Cleaned Up Project Updated BOM Updated Naming
    [NMEA-2000-BUS-Voltage-BOM.csv, NMEA-2000-BUS-Voltage.csv, NMEA-2000-BUS-Voltage.kicad_pcb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]
